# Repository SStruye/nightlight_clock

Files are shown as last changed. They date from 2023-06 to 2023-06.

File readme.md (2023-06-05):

# dimmable nightlight + clock using ESP12F(ESP8266)
This PCB design was an idea for a night light in combination with a clock. I found an old 4x40 LCD panel to use as display.
# PCB desing
- for the dimmable light i used a triac dimmer circuit.
- To save pins i used a multiplexer for the LCD.
- I also added a header that can be used for a rotary encoder and a header that can be used for an I2C temperature sensor or something else using I2C.

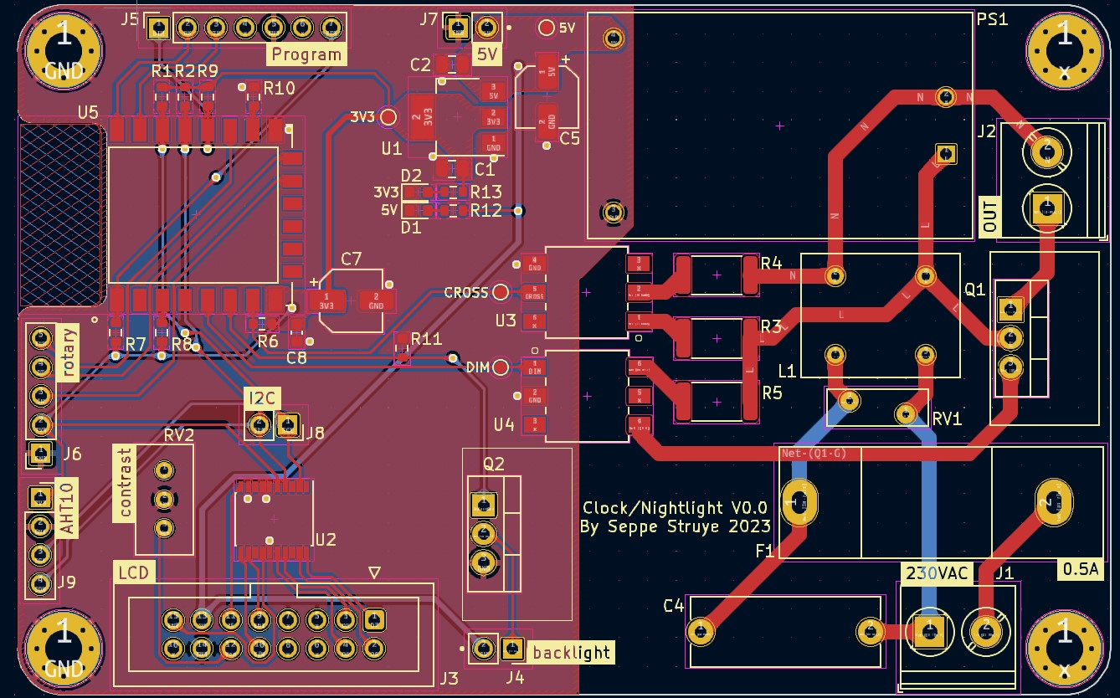
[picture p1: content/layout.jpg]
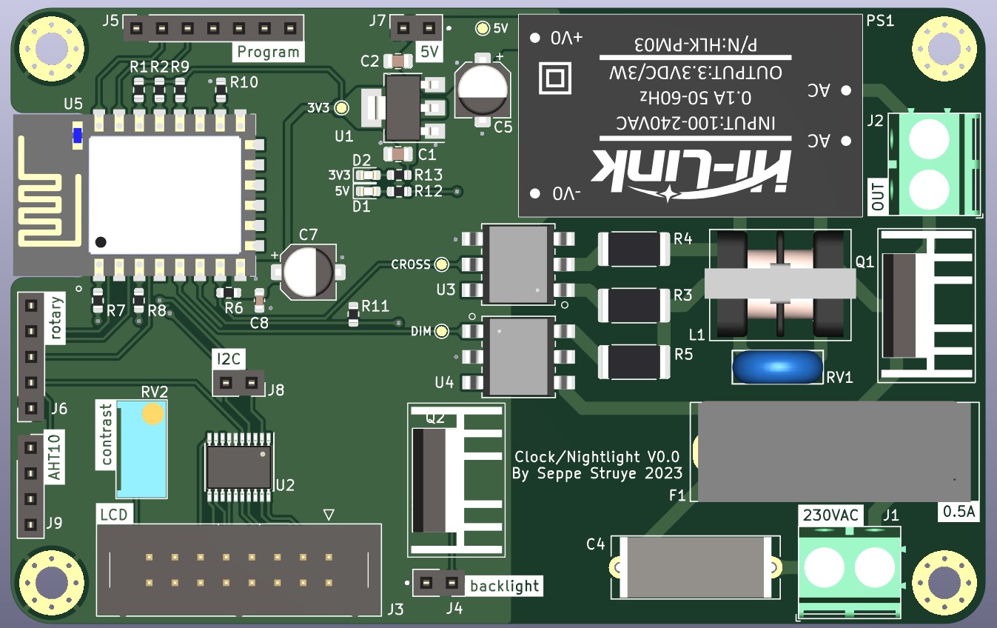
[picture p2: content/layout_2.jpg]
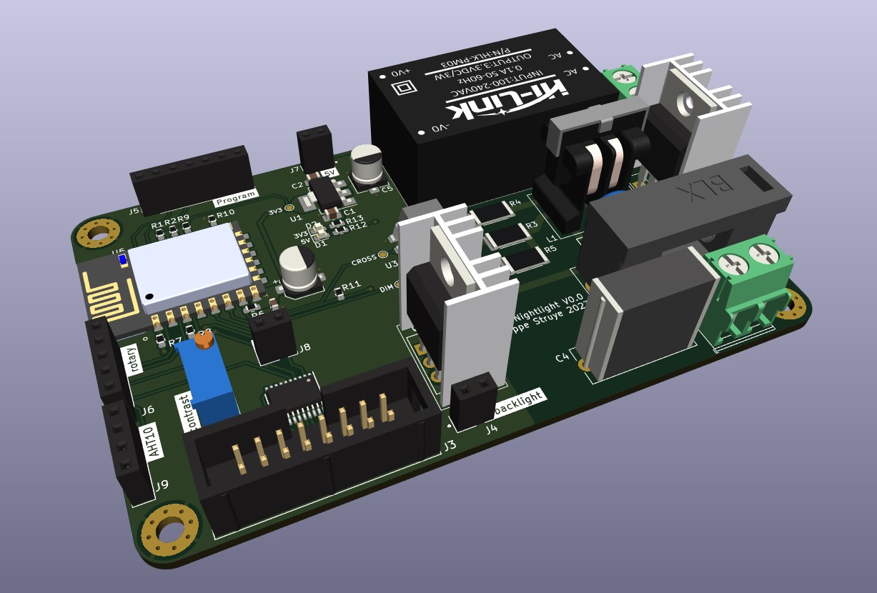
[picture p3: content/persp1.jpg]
  

# software
- I had to edit the arduino liquidcrystal-I2C library to accomodate for the LCD using two LCD drivers. 1 for the top 2 rows and one for the bottom 2 rows. If i hadn't used a multiplexer
this wouldn't have been necessary.
- DMC40457_clock is a library i created to handle te logic behind the displaying of characters on to the lcd.
- clock_software.ino is the arduino sketch that runs on the ESP12F.

## result
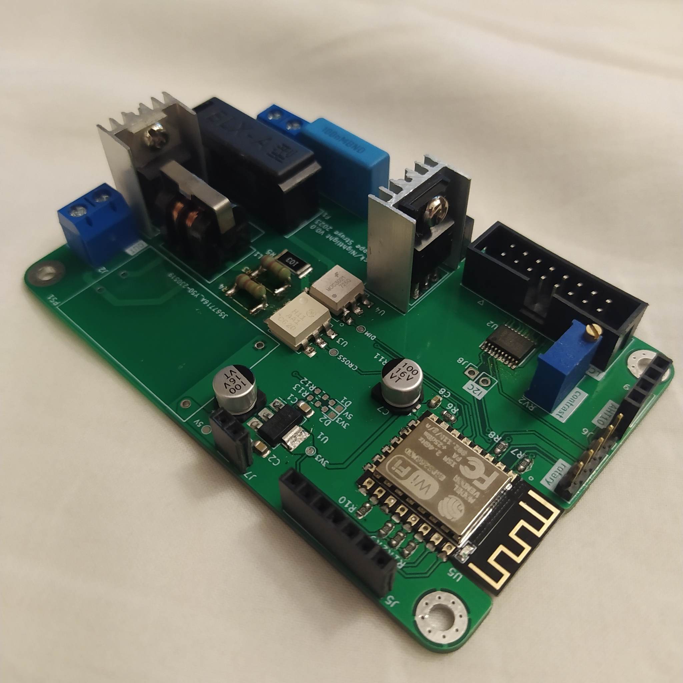
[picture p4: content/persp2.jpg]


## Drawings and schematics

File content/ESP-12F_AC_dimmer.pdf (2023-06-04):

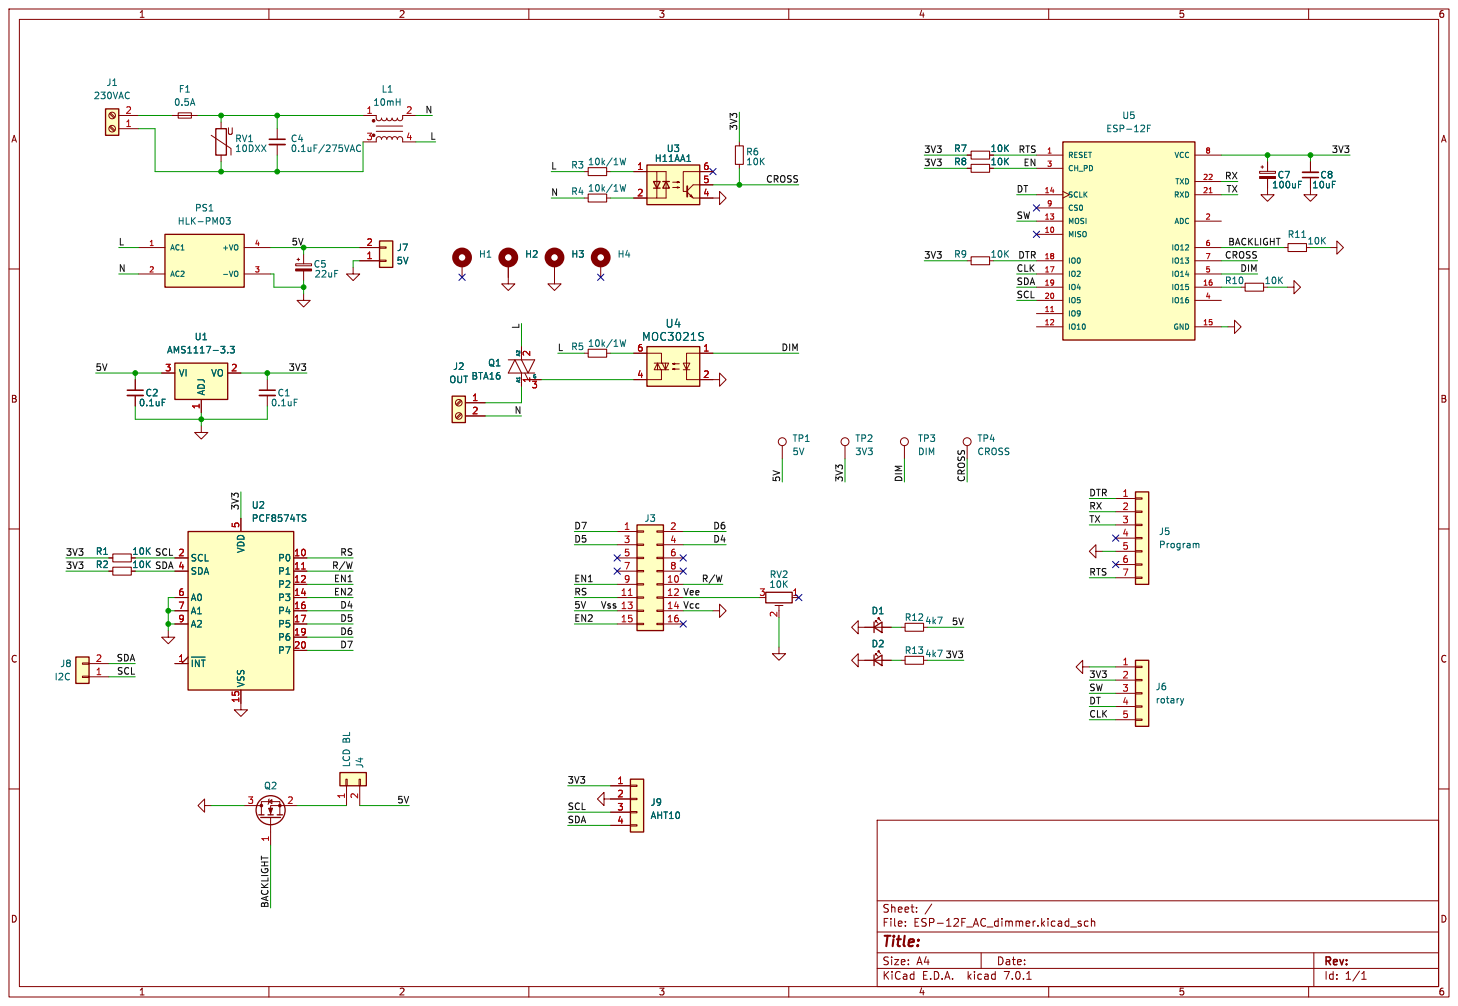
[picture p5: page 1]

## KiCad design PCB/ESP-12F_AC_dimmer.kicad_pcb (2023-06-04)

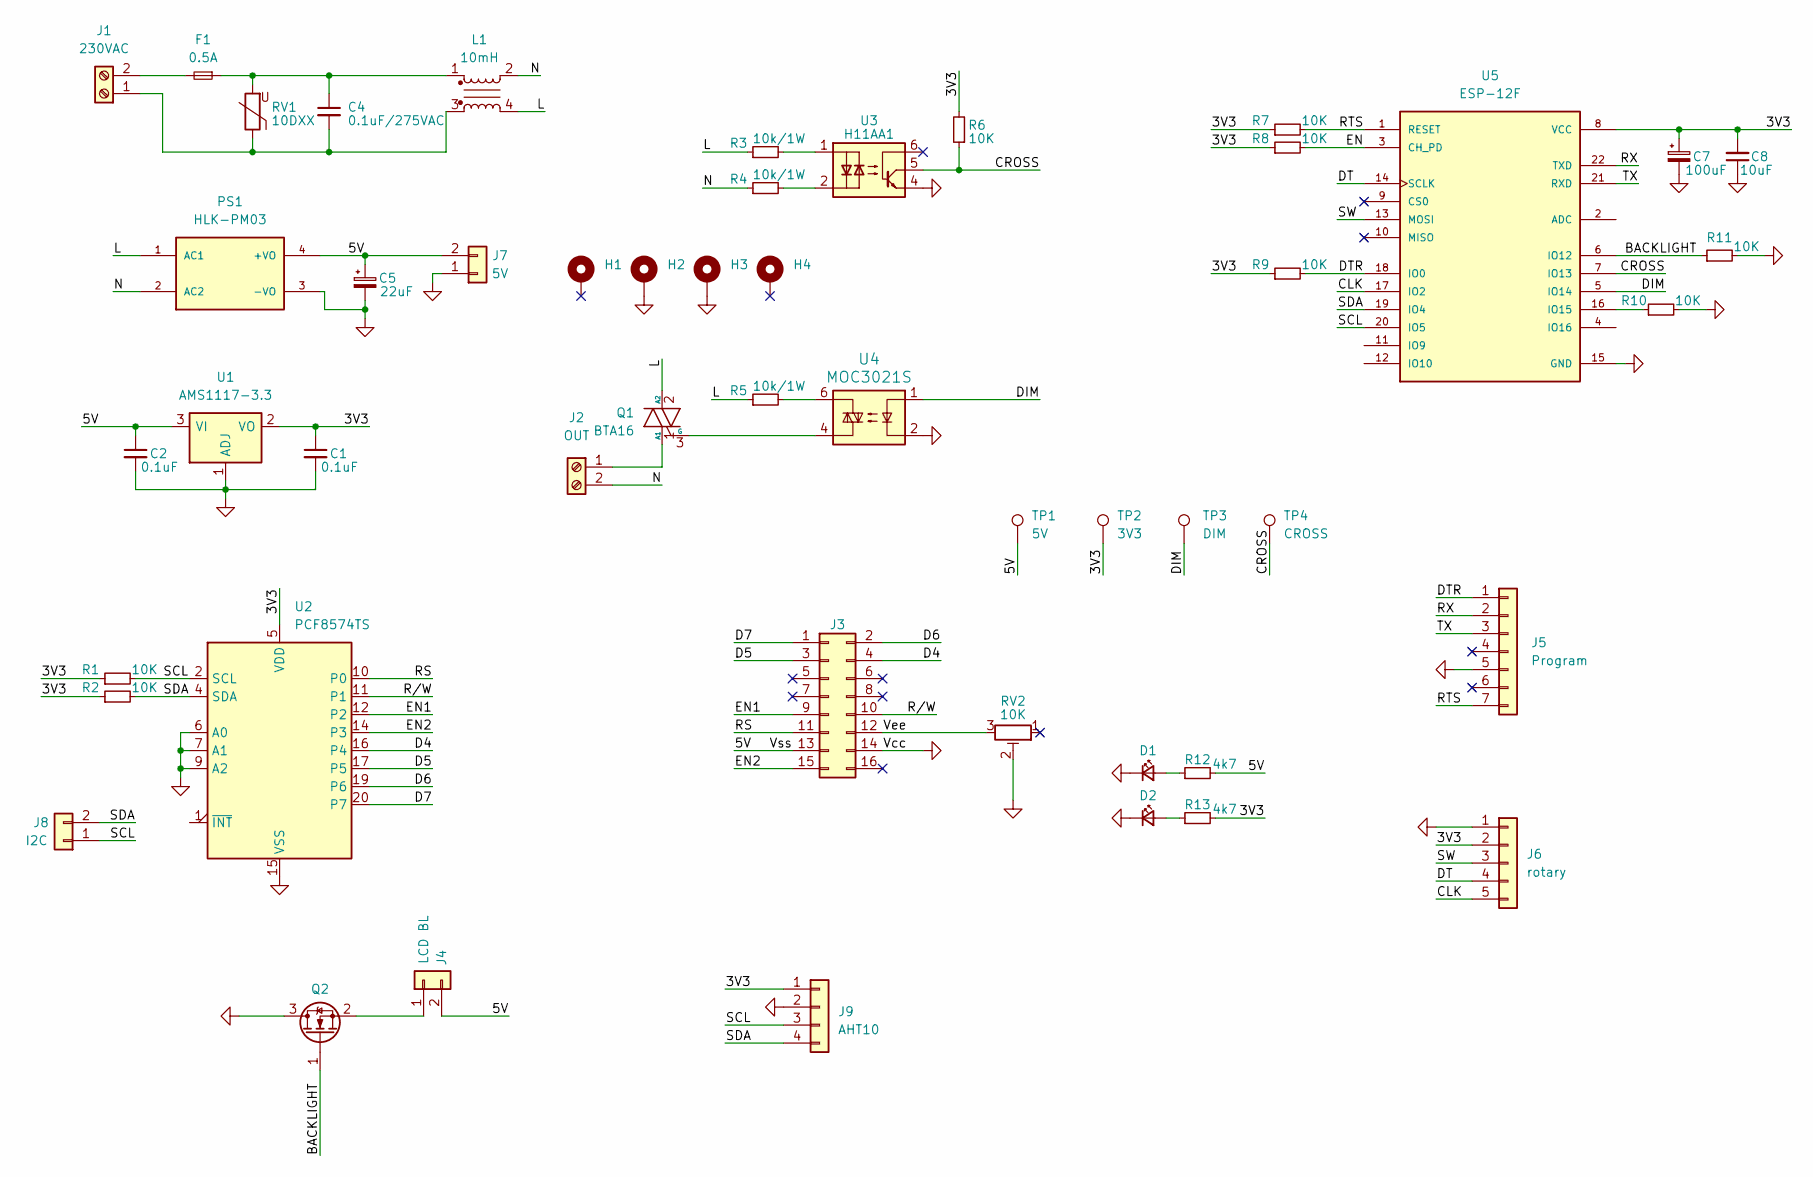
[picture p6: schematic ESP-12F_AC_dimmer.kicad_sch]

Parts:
C1, C2: 0.1uF; C_0805_2012Metric
C4: 0.1uF/275VAC; C_Rect_L16.5mm_W6.0mm_P15.00mm_MKT
C5: 22uF; CP_Elec_5x5.4
C7: 100uF; CP_Elec_5x5.4
C8: 10uF; C_0603_1608Metric
D1, D2: LED_Small; LED_0603_1608Metric
F1: 0.5A; BLX-A
H1, H2, H3, H4: MountingHole_Pad; MountingHole_3.2mm_M3_Pad_Via
J1: 230VAC; TerminalBlock_Phoenix_PT-1,5-2-5.0-H_1x02_P5.00mm_Horizontal
J2: OUT; TerminalBlock_Phoenix_PT-1,5-2-5.0-H_1x02_P5.00mm_Horizontal
J3: LCD; IDC-Header_2x08_P2.54mm_Vertical
J4: LCD BL; PinSocket_1x02_P2.54mm_Vertical
J5: Program; PinSocket_1x07_P2.54mm_Vertical
J6: rotary; PinSocket_1x05_P2.54mm_Vertical
J7: 5V; PinSocket_1x02_P2.54mm_Vertical
J8: I2C; PinSocket_1x02_P2.54mm_Vertical
J9: AHT10; PinSocket_1x04_P2.54mm_Vertical
L1: 10mH; choke
PS1: HLK-PM03; CONV_HLK-PM03
Q1: BTA16; TO-220-3_Vertical_2
Q2: K1459; TO-220-3_Vertical
R1, R2, R6, R7, R8, R9, R10, R11: 10K; R_0603_1608Metric
R3, R4, R5: 10k/1W; R_2512_6332Metric
R12, R13: 4k7; R_0603_1608Metric
RV1: 10DXX; RV_Disc_D9mm_W3.3mm_P5mm
RV2: 10K; Potentiometer_Bourns_3296W_Vertical
TP1: 5V; TestPoint_Pad_D1.0mm
TP2: 3V3; TestPoint_Pad_D1.0mm
TP3: DIM; TestPoint_Pad_D1.0mm
TP4: CROSS; TestPoint_Pad_D1.0mm
U1: AMS1117-3.3; SOT-223-3_TabPin2
U2: PCF8574TS; SSOP-20_4.4x6.5mm_P0.65mm
U3: H11AA1; MOC3021S
U4: MOC3021S
U5: ESP-12F; XCVR_ESP8266-12E_ESP-12E

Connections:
/3V3: C1.1, C7.1, C8.2, J6.2, J9.1, R1.1, R2.1, R6.2, R7.1, R8.1, R9.1, R13.2, TP2.1, U1.2 (VO), U2.5 (VDD), U5.8 (VCC)
/5V: C2.1, C5.1, J3.13, J4.2, J7.2, PS1.4 (+VO), R12.2, TP1.1, U1.3 (VI)
/BACKLIGHT: Q2.1 (G), R11.1, U5.6 (IO12)
/CLK: J6.5, U5.17 (IO2)
/CROSS: R6.1, TP4.1, U3.5, U5.7 (IO13)
/D4: J3.4, U2.16 (P4)
/D5: J3.3, U2.17 (P5)
/D6: J3.2, U2.19 (P6)
/D7: J3.1, U2.20 (P7)
/DIM: TP3.1, U4.1, U5.5 (IO14)
/DT: J6.4, U5.14 (SCLK)
/DTR: J5.1, R9.2, U5.18 (IO0)
/EN: R8.2, U5.3 (CH_PD)
/EN1: J3.9, U2.12 (P2)
/EN2: J3.15, U2.14 (P3)
/L: L1.4, PS1.1 (AC1), Q1.2 (A2), R3.1, R5.1
/N: J2.2, L1.2, PS1.2 (AC2), R4.1
/RS: J3.11, U2.10 (P0)
/RTS: J5.7, R7.2, U5.1 (RESET)
/RX: J5.2, U5.22 (TXD)
/R/W: J3.10, U2.11 (P1)
/SCL: J8.1, J9.3, R1.2, U2.2 (SCL), U5.20 (IO5)
/SDA: J8.2, J9.4, R2.2, U2.4 (SDA), U5.19 (IO4)
/SW: J6.3, U5.13 (MOSI)
/TX: J5.3, U5.21 (RXD)
/Vee: J3.12, RV2.3
GND: C1.2, C2.2, C5.2, C7.2, C8.1, D1.1 (K), D2.1 (K), H2.1, H3.1, J3.14, J5.5, J6.1, J7.1, J9.2, PS1.3 (-VO), Q2.3 (D), R10.2, R11.2, RV2.2, U1.1 (ADJ), U2.6 (A0), U2.7 (A1), U2.9 (A2), U2.15 (VSS), U3.4, U4.2, U5.15 (GND)
unnamed: C4.1, F1.1, L1.1, RV1.2
unnamed: D1.2 (A), R12.1
unnamed: D2.2 (A), R13.1
unnamed: C4.2, J1.1, L1.3, RV1.1
unnamed: F1.2, J1.2
unnamed: J2.1, Q1.1 (A1)
unnamed: J4.1, Q2.2 (S)
unnamed: Q1.3 (G), U4.4
unnamed: R3.2, U3.1
unnamed: R4.2, U3.2
unnamed: R5.2, U4.6
unnamed: R10.1, U5.16 (IO15)

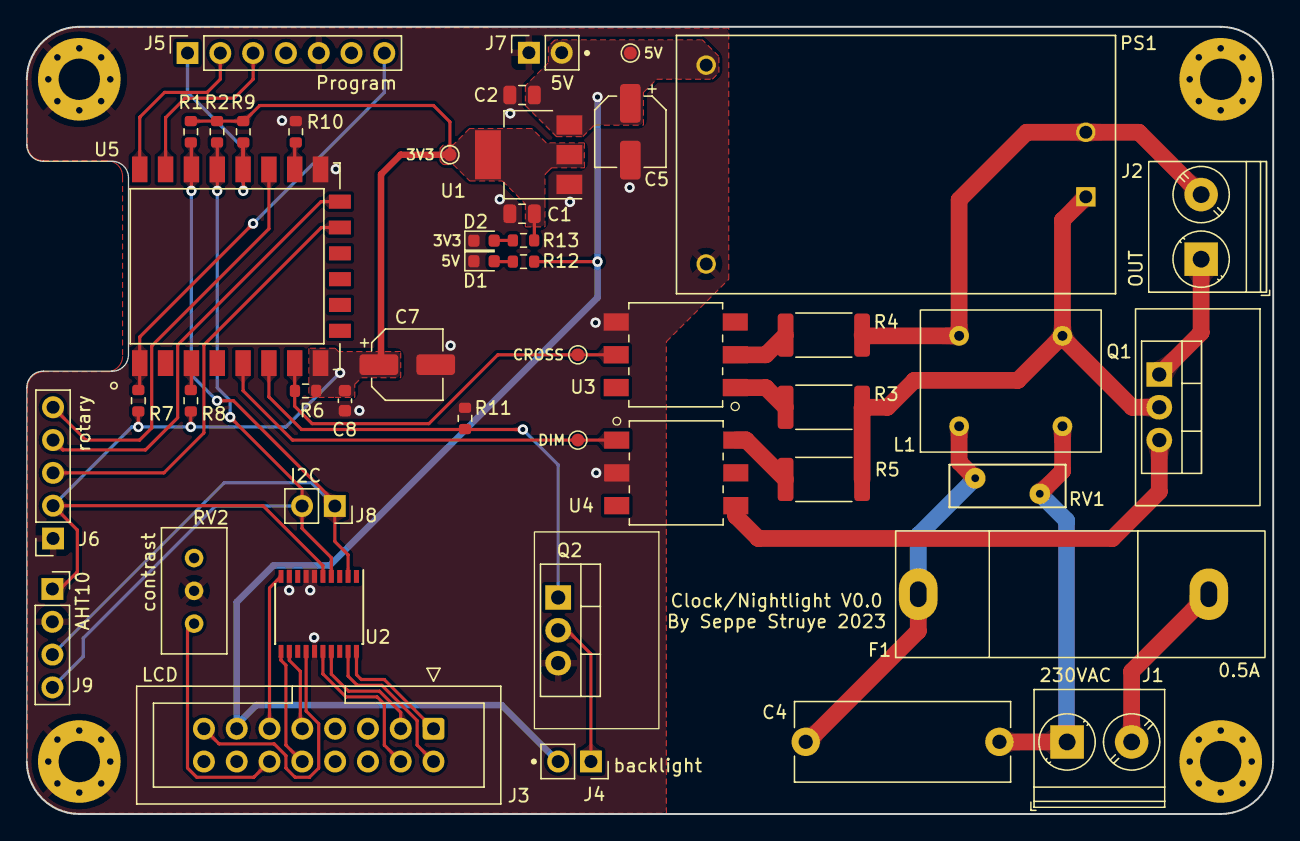
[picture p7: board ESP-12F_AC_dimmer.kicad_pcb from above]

Board: 2 copper layers, 96.5 x 61.0 mm, 50 parts (0 on the bottom side), 39 nets.

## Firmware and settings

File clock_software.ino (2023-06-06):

#include "DMC40457_clock.h"
#include <NTPClient.h>
#include <ESP8266WiFi.h>
#include <WiFiUdp.h>
#include <Ticker.h>
#include <Adafruit_AHT10.h>

// sens
Adafruit_AHT10 aht;

// display
DMC40457_clock display(0x20,40,4);

// wifi for time
const char *ssid     = "";
const char *password = "";
const long  utcOffsetInSeconds = 3600;
bool update_display_flag = false;
Ticker timer;
WiFiUDP ntpUDP;
NTPClient timeClient(ntpUDP, "ntp.telenet.be", utcOffsetInSeconds*2);

// dimmable light
const int zero_cross = 13;
const int triac_pin  = 14;
const int rot_1 = 1;
const int rot_2 = 3;
const int rot_B = 2;
int dim_value = 0;
bool light_on = false;
int last_btn_debounce = 0;
const int btn_debounce_time = 500;

// interrupt handlers
void ICACHE_RAM_ATTR trigger_triac();
void ICACHE_RAM_ATTR dim_light();
void ICACHE_RAM_ATTR toggle_light();
void update_display_ISR();

void setup() {
  Serial.begin(115200);
  
  // temp sens
  aht.begin();
  
  // display
  display.begin();

  // time
  WiFi.begin(ssid,password);
  connect_wifi();
  timeClient.begin();
  timer.attach_ms(10000, update_display_ISR);

  // dimmable light
  pinMode(triac_pin, OUTPUT);
  pinMode(rot_1, INPUT);
  pinMode(rot_2, INPUT);
  pinMode(rot_B, INPUT);
  attachInterrupt(digitalPinToInterrupt(rot_1), dim_light, CHANGE);
  attachInterrupt(digitalPinToInterrupt(rot_B), toggle_light, FALLING);
  update_display();
}

void loop() {
  // put your main code here, to run repeatedly:
  if(update_display_flag){update_display();}
}

void update_display(){

  sensors_event_t humidity, temp;
  aht.getEvent(&humidity, &temp);

  if(!timeClient.update()){return;}
  int hours   = timeClient.getHours();
  int minutes = timeClient.getMinutes();
  display.update(hours, minutes, (int)temp.temperature);
  update_display_flag = false;
}
// time
void connect_wifi(){
  while(WiFi.status() != WL_CONNECTED){
    delay(500);
    Serial.print("."); 
  }
}

void update_display_ISR(){
  update_display_flag = true;
}


// dimmable light interrupts
void trigger_triac(){
  delayMicroseconds(map(dim_value,0,200,10,6500)); // read AD1 
  digitalWrite(triac_pin, HIGH);
  delayMicroseconds(10);  
  digitalWrite(triac_pin, LOW);
} 

void dim_light(){
  if((digitalRead(rot_1) != digitalRead(rot_2)) && dim_value > 0){
    dim_value--;
  }else if(dim_value < 200){
    dim_value++;
  }
}

void toggle_light(){
  if(millis() - last_btn_debounce < btn_debounce_time){
    return;
  }
  last_btn_debounce = millis();
  if(light_on){
    detachInterrupt(digitalPinToInterrupt(zero_cross));
  }else{
    attachInterrupt(digitalPinToInterrupt(zero_cross), trigger_triac, FALLING);
  }
  light_on = !light_on;
}
